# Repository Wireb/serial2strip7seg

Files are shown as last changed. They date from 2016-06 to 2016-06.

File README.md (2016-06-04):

### Serial to dual 7 segment display led strip driver

This driver is a serial input to dual 7 segment display driver. 

####Inputs:
Synchronous serial input signals 
  Data in
  Serial clock
  Reset
  Latch data
  
####Outputs:
Synchronous serial outputs signals 
  Data out
  Serial clock
  Reset
  Latch data
LED strip outputs
  14x 2.3A @ 20V max (not including thermal limits)
  
####Power:
Logic and serial intputs/outputs can be run off 3.3V or 5V   
LED side only needs a ground connection
!!NOTE!! logic and led grounds are connected. Make sure the LED grounds are large enough to carry all the current of the LED strips. Also watch out for ground loops.

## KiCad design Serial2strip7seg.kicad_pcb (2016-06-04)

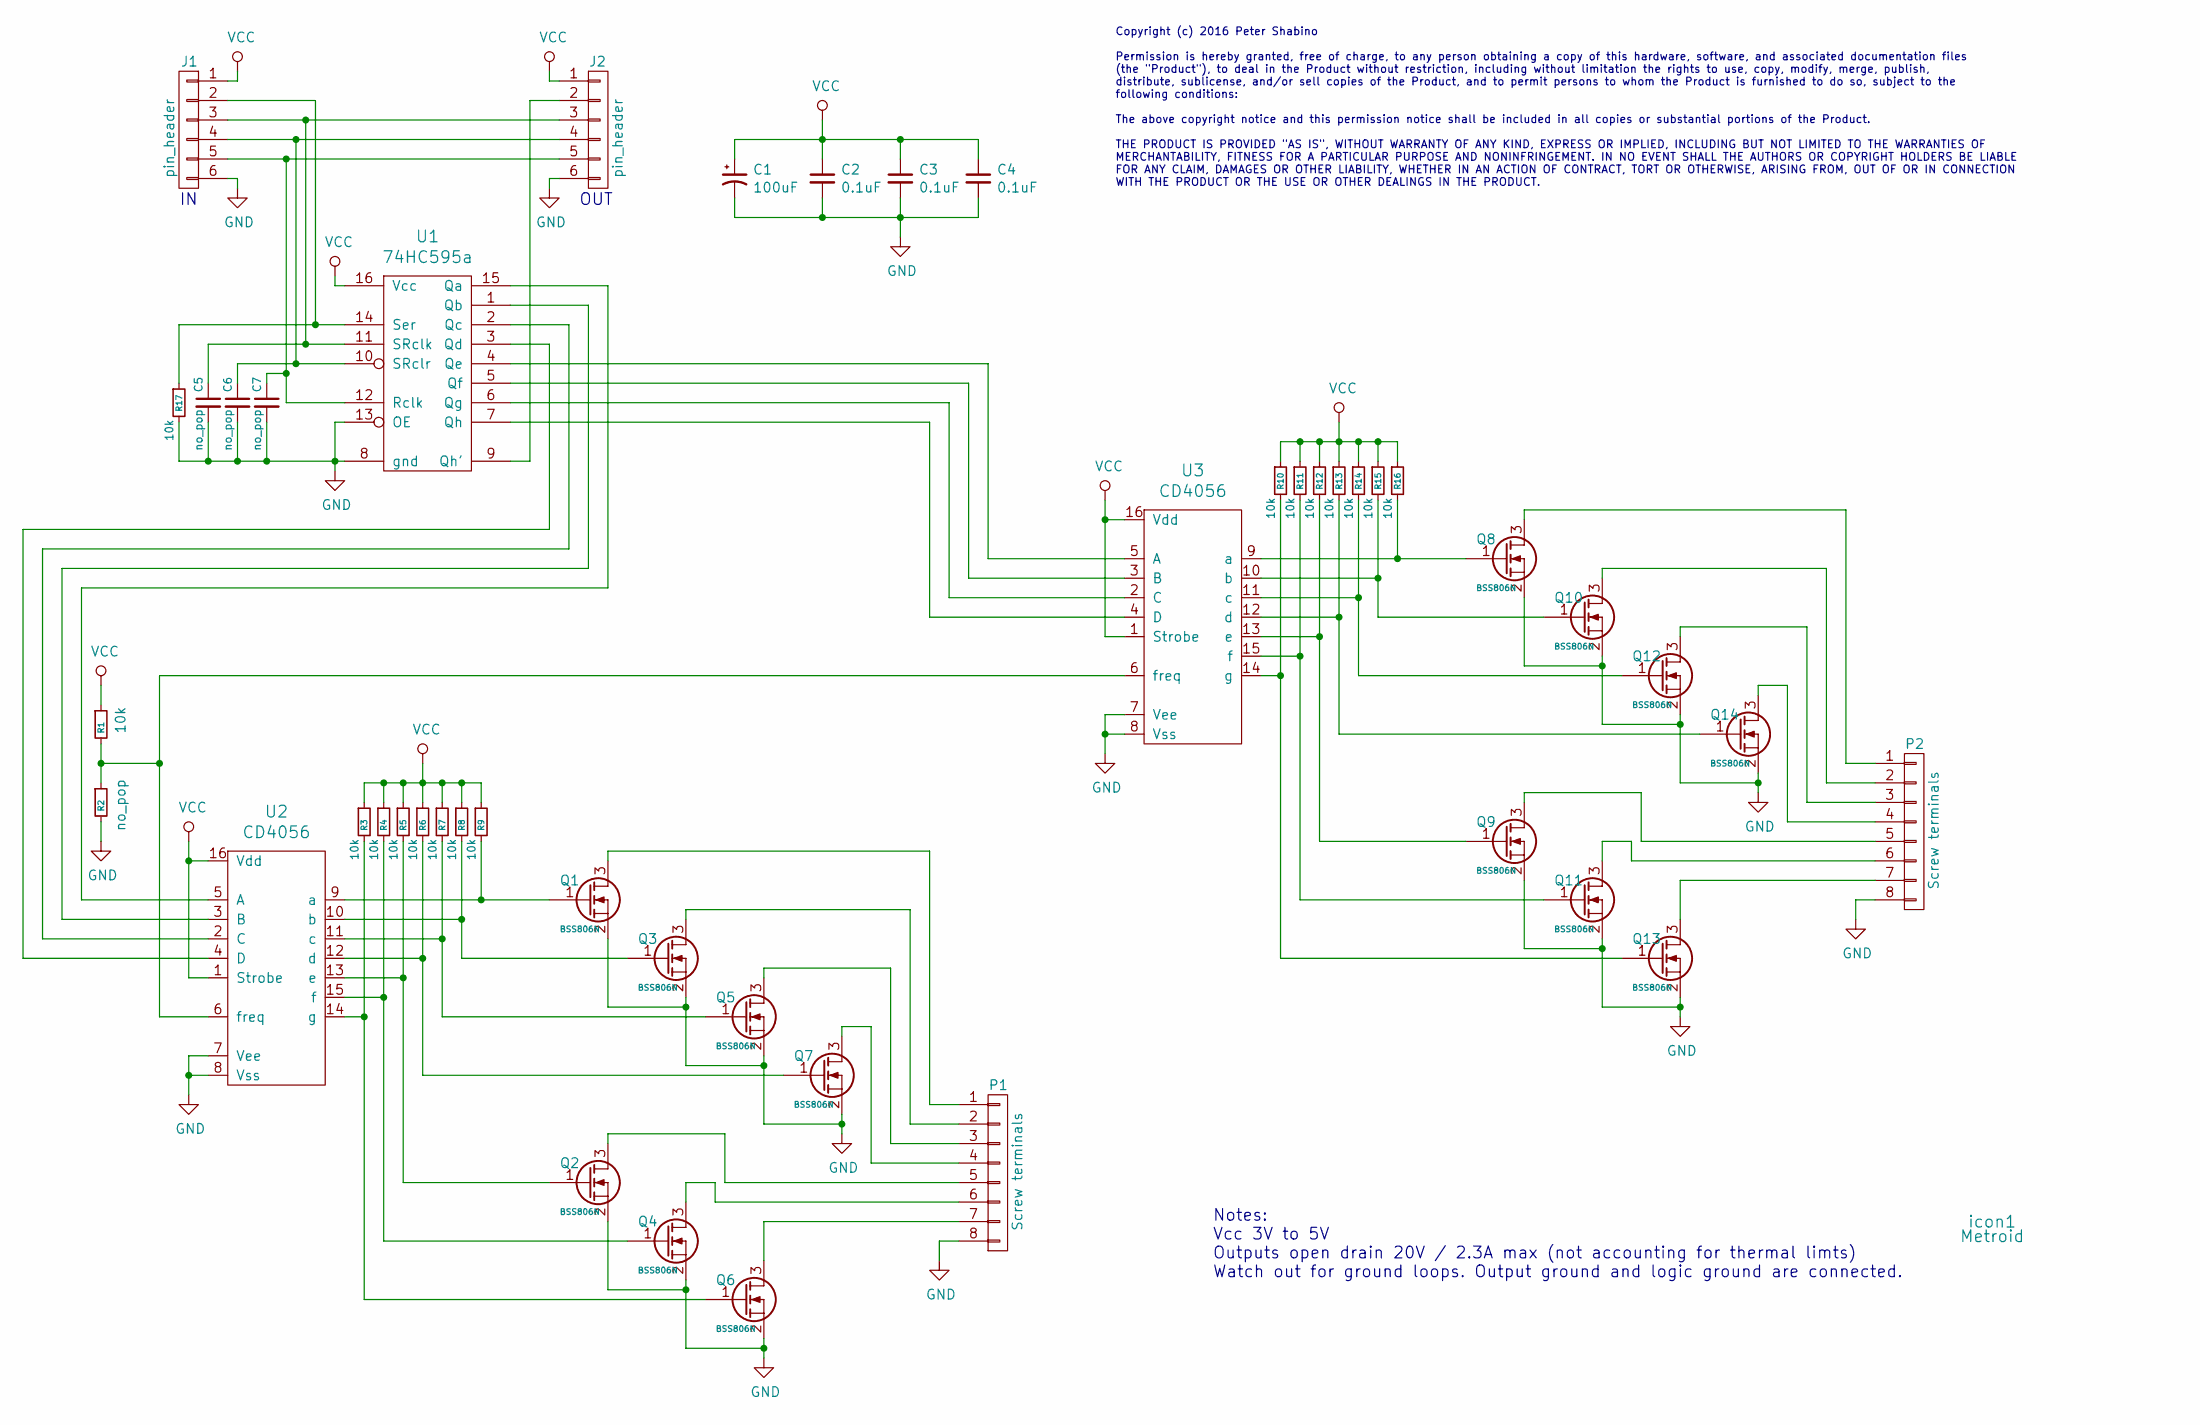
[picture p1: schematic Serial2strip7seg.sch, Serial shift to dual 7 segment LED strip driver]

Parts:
C1: 100uF; C_Radial_D5_L11_P2.5
C2, C3, C4: 0.1uF; C_0805
C5, C6, C7: no_pop; C_0805
J1, J2: pin_header; Pin_Header_Straight_1x06
P1, P2: Screw terminals; DG301-5.008P-12
Q1, Q2, Q3, Q4, Q5, Q6, Q7, Q8, Q9, Q10, Q11, Q12, Q13, Q14: BSS806N; SOT-23
R1, R3, R4, R5, R6, R7, R8, R9, R10, R11, R12, R13, R14, R15, R16, R17: 10k; R_0805
R2: no_pop; R_0805
U1: 74HC595a; SOIC-16_3.9x9.9mm_Pitch1.27mm
U2, U3: CD4056; SOIC-16_3.9x9.9mm_Pitch1.27mm
icon1: Metroid; metroid

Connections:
GND: C1.2, C2.2, C3.2, C4.2, C5.2, C6.2, C7.2, J1.6, J2.6, P1.8, P2.8, Q1.2 (S), Q2.2 (S), Q3.2 (S), Q4.2 (S), Q5.2 (S), Q6.2 (S), Q7.2 (S), Q8.2 (S), Q9.2 (S), Q10.2 (S), Q11.2 (S), Q12.2 (S), Q13.2 (S), Q14.2 (S), R2.2, R17.2, U1.8 (gnd), U1.13 (OE), U2.7 (Vee), U2.8 (Vss), U3.7 (Vee), U3.8 (Vss)
unnamed: C5.1, J1.3, J2.3, U1.11 (SRclk)
unnamed: C6.1, J1.4, J2.4, U1.10 (SRclr)
unnamed: C7.1, J1.5, J2.5, U1.12 (Rclk)
unnamed: J1.2, R17.1, U1.14 (Ser)
unnamed: J2.2, U1.9 (Qh')
unnamed: P1.1, Q1.3 (D)
unnamed: P1.2, Q3.3 (D)
unnamed: P1.3, Q5.3 (D)
unnamed: P1.4, Q7.3 (D)
unnamed: P1.5, Q2.3 (D)
unnamed: P1.6, Q4.3 (D)
unnamed: P1.7, Q6.3 (D)
unnamed: P2.1, Q8.3 (D)
unnamed: P2.2, Q10.3 (D)
unnamed: P2.3, Q12.3 (D)
unnamed: P2.4, Q14.3 (D)
unnamed: P2.5, Q9.3 (D)
unnamed: P2.6, Q11.3 (D)
unnamed: P2.7, Q13.3 (D)
unnamed: Q1.1 (G), R9.2, U2.9 (a)
unnamed: Q2.1 (G), R5.2, U2.13 (e)
unnamed: Q3.1 (G), R8.2, U2.10 (b)
unnamed: Q4.1 (G), R4.2, U2.15 (f)
unnamed: Q5.1 (G), R7.2, U2.11 (c)
unnamed: Q6.1 (G), R3.2, U2.14 (g)
unnamed: Q7.1 (G), R6.2, U2.12 (d)
unnamed: Q8.1 (G), R16.2, U3.9 (a)
unnamed: Q9.1 (G), R12.2, U3.13 (e)
unnamed: Q10.1 (G), R15.2, U3.10 (b)
unnamed: Q11.1 (G), R11.2, U3.15 (f)
unnamed: Q12.1 (G), R14.2, U3.11 (c)
unnamed: Q13.1 (G), R10.2, U3.14 (g)
unnamed: Q14.1 (G), R13.2, U3.12 (d)
unnamed: R1.2, R2.1, U2.6 (freq), U3.6 (freq)
unnamed: U1.1 (Qb), U2.3 (B)
unnamed: U1.2 (Qc), U2.2 (C)
unnamed: U1.3 (Qd), U2.4 (D)
unnamed: U1.4 (Qe), U3.5 (A)
unnamed: U1.5 (Qf), U3.3 (B)
unnamed: U1.6 (Qg), U3.2 (C)
unnamed: U1.7 (Qh), U3.4 (D)
unnamed: U1.15 (Qa), U2.5 (A)
VCC: C1.1, C2.1, C3.1, C4.1, J1.1, J2.1, R1.1, R3.1, R4.1, R5.1, R6.1, R7.1, R8.1, R9.1, R10.1, R11.1, R12.1, R13.1, R14.1, R15.1, R16.1, U1.16 (Vcc), U2.1 (Strobe), U2.16 (Vdd), U3.1 (Strobe), U3.16 (Vdd)

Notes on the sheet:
OUT
Notes: Vcc 3V to 5V Outputs open drain 20V / 2.3A max (not accounting for thermal limts) Watch out for ground loops. Output ground and logic ground are connected.
Copyright (c) 2016 Peter Shabino Permission is hereby granted, free of charge, to any person obtaining a copy of this hardware, software, and associated documentation files (the "Product"), to deal in the Product without restriction, including without limitation the rights to use, copy, modify, mer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

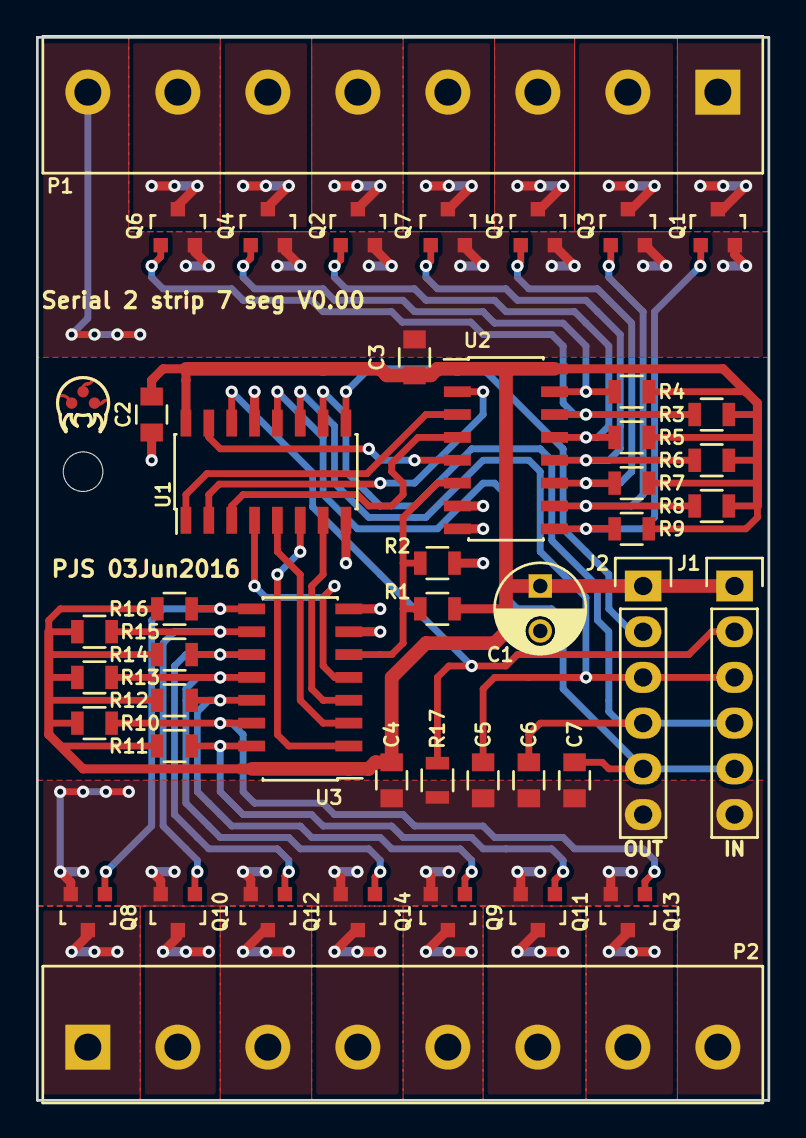
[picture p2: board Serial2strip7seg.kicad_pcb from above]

Board: 2 copper layers, 40.6 x 59.1 mm, 46 parts (0 on the bottom side), 44 nets.
